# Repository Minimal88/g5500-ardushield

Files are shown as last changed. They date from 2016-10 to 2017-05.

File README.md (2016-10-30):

# G5500-ardushield
An arduino shield for controlling a Yaesu G5000 rotator.

## Intro
This is a simple Arduino Shield (compatible for any Duemilenove or Uno like boards) for controlling a Yaesu G5500 Antenna rotator.

This shield is designed to be used with K3NG Rotator controller software (flashed on arduino) which you can find [here](https://github.com/k3ng/k3ng_rotator_controller).
For the specific configuration please have a look on the branch maintained for this [here](https://github.com/ppapadeas/k3ng_rotator_controller/tree/lsf-g5500).

## Instructions

You have a couple of different options for producing this shield:
* Download the release file for off-the-shelf gerber files for local production.
* Or order the board directly from [OSHPark](https://oshpark.com/shared_projects/pu8Rst2N)
* Or download the sourcefiles from the repo and adjust them to your needs

Once you have a board ready make sure to flash the board with the K3NG software, properly configured for the pins assigned to each function.

You can see some pictures of the board homebrewed [here](https://goo.gl/photos/bw671UsoGTs3t2yWA).

## Contribute

Please open a github issue for any suggestions or bugs you find.

## License

This work is released under CERN Open Hardware Licence v1.2
Copyright 2016 Libre Space Foundation

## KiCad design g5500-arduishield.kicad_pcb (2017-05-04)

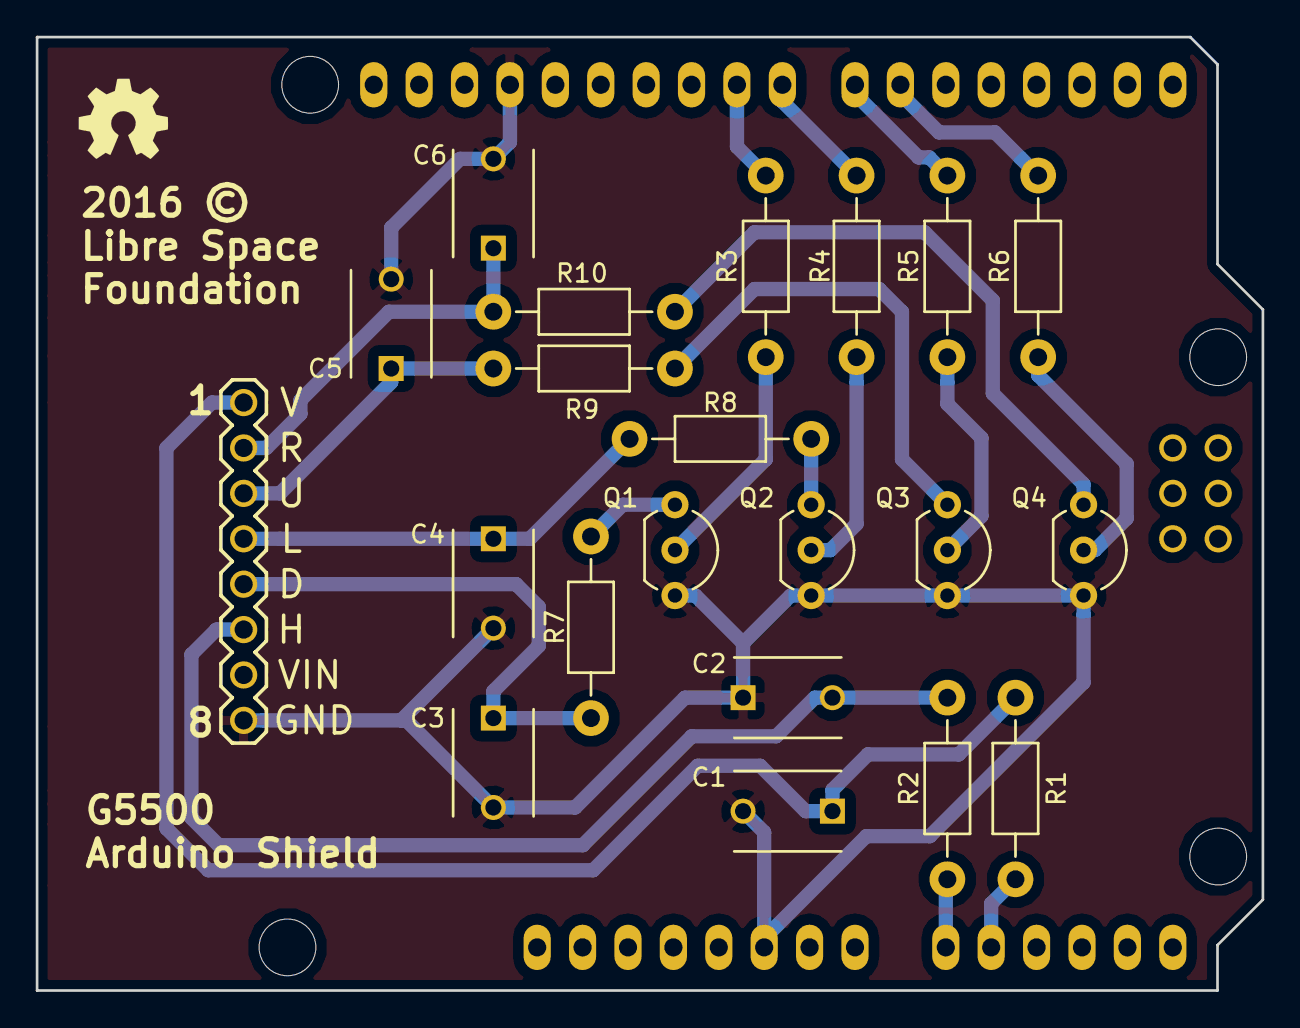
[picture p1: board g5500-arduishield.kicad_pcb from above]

Board: 2 copper layers, 68.6 x 53.3 mm, 23 parts (0 on the bottom side), 21 nets.

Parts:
C1, C2, C3, C4, C5, C6: 10n; C_Disc_D6_P5
JP1: M08; 1X08
LOGO_OSHW_silkscreen_5mm: val**; LOGO_OSHW_silkscreen_5mm
Q1, Q2, Q3, Q4: PN2222A; TO-92_Inline_Wide
R1, R2, R3, R4, R5, R6: 1K; Resistor_Horizontal_RM10mm
R7, R8, R9, R10: 33K; Resistor_Horizontal_RM10mm
SHIELD1: ARDUINO_SHIELD

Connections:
D: C3.1, JP1.5, R7.1
GND: C1.2, C2.1, C3.2, C4.2, C5.2, C6.2, JP1.8, Q1.3, Q2.3, Q3.3, Q4.3, SHIELD1.GND1, SHIELD1.GND3
H: C1.1, JP1.1, R1.1
L: C4.1, JP1.4, R8.1
unnamed: Q1.1, R7.2
unnamed: Q1.2, R3.1
unnamed: Q2.1, R8.2
unnamed: Q2.2, R4.1
unnamed: Q3.1, R9.2
unnamed: Q3.2, R5.1
unnamed: Q4.1, R10.2
unnamed: Q4.2, R6.1
unnamed: R1.2, SHIELD1.AD1
unnamed: R2.2, SHIELD1.AD0
unnamed: R3.2, SHIELD1.9
unnamed: R4.2, SHIELD1.8
unnamed: R5.2, SHIELD1.7
unnamed: R6.2, SHIELD1.6
R: C6.1, JP1.2, R10.1
U: C5.1, JP1.3, R9.1
V: C2.2, JP1.6, R2.1

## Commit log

2016-01-01 First take on controller shield
    [g5500-arduishield.kicad_pcb, g5500-arduishield.sch]
2017-02-28 Add gerber files
    [g5500-arduishield-B.Cu.gbr, g5500-arduishield-B.Mask.gbr, g5500-arduishield-B.Paste.gbr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]
2017-05-04 Add slight routing adjustments and addition of F.Cu GND zone
    [g5500-arduishield-B.Paste.gbr, g5500-arduishield-F.Mask.gbr, g5500-arduishield-F.Paste.gbr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]
